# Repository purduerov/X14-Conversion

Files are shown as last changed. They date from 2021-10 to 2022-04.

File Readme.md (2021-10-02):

# Readme for X14-Conversion

Whenever you make a new part, download the datasheet and save it here _**and**_ with the part in the parts library

Always pull other people's changes before beginning to work
`git pull`

Be sure to push your changes after  working on them. Run:
1. `git add .` to add any files in this directory or a subdirectory
or `git add -u` to add any modified files
2. (Optional) `git clean -nX` to see what ignored files can be removed
	`git clean -fX` removes ignored files (Eagle backups)
3. `git commit -m "helpful commit message"` with a description of the work that you did
4. `git push` to push your work to github

Other helpful commands
* `git status` says information about modified and staged files
* `git log` shows the recent commits of the repository
* `git log filename.extension` show the recent commits for just that file
* `git checkout first-couple-letter-of-commit-id` lets you go back to a previous version
* `git checkout master` brings you back to the latest commit
* `git tag` lists the tags
* `git tag -a orderX -m "the version of the board placed for the X'th order"` tag a specific commit
* `git push --tags` needed to push tags to remote
* `git show orderX` show the commit log for the given tag
* `git checkout orderX` go back and interact with the files at the tagged commit

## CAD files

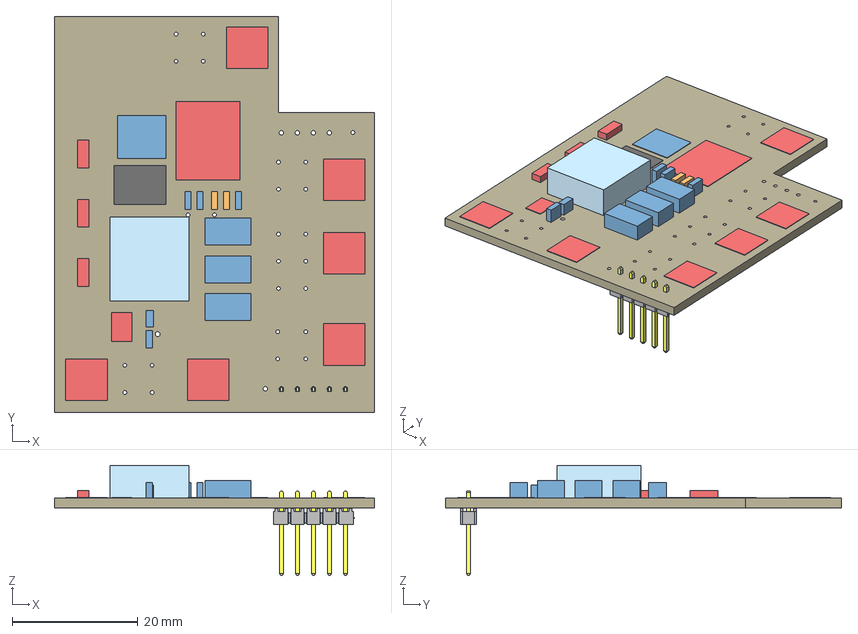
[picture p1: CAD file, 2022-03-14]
X14-Conversion.step
50.8 x 62.9 x 17.5 mm
Board
15uH
AZ1117C-3.3
3.3V_TESTPOINT
5.2V_TESTPOINT
12V_TESTPOINT
GND_TESTPOINT x 3
1kΩ x 2
0.1uF x 4
22uF
550mV 5A
120uF 25mΩ
_TSW-105-14-G-S_body
_T-1S6-08-TSW-1-14-5-S
BUCK,LM2678S-ADJ
150uF x 3
1X02 x 3

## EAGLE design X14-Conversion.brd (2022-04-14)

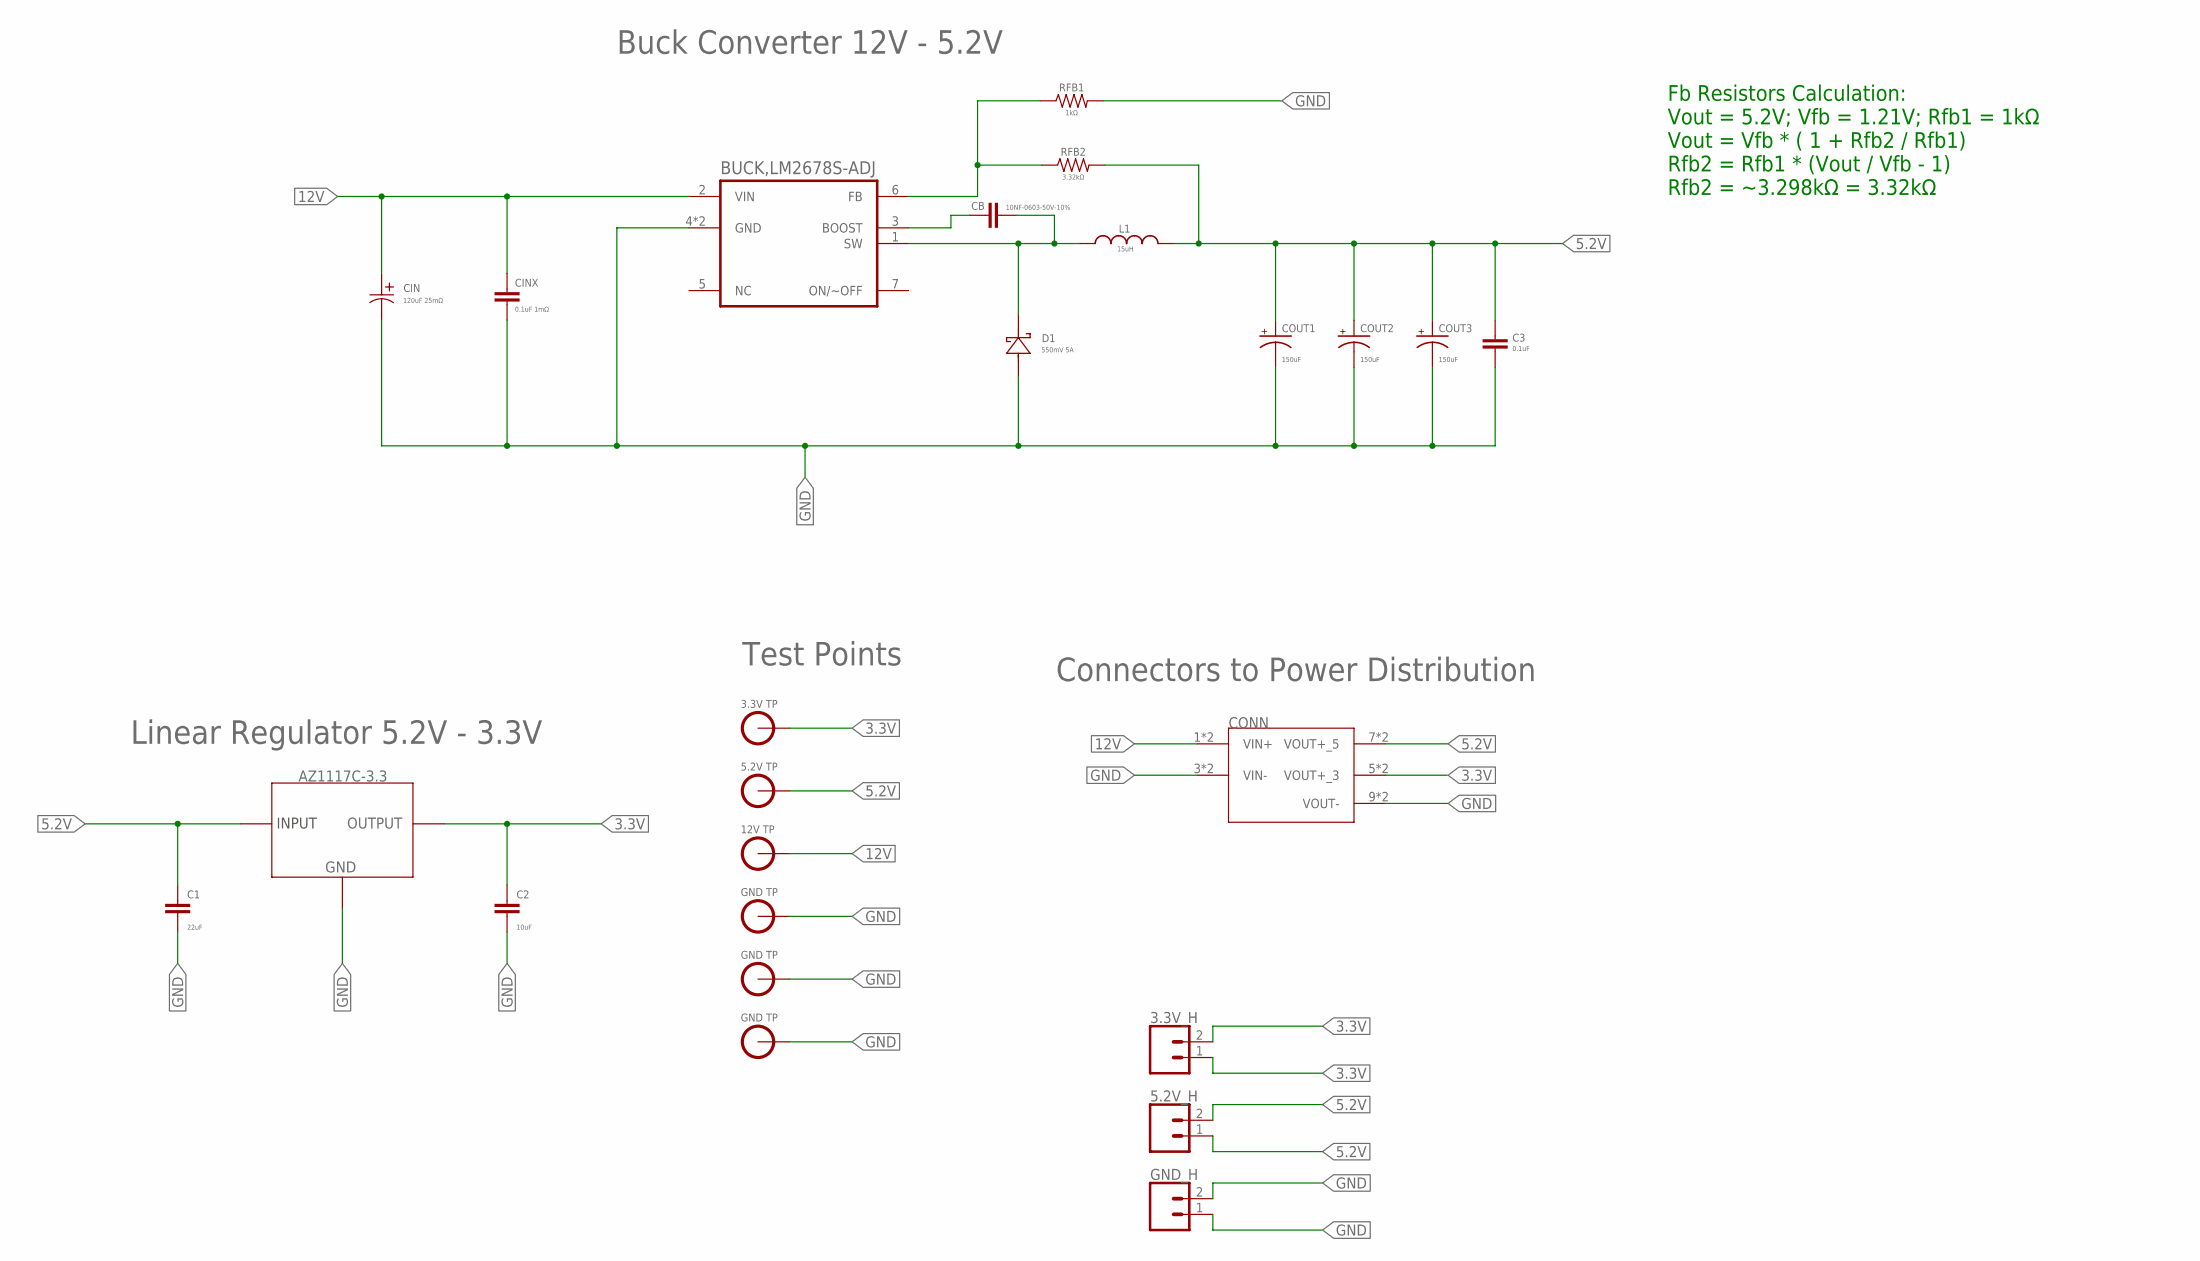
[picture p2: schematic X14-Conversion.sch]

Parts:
3.3V_H, 5.2V_H: CONN_02; 1X02
AZ1117C: AZ1117C-3.3; SOT150P410X160-3N
C1: 22uF; 0805
C2: 10uF; 0603
C3: 0.1uF; 0603
CB: 10NF-0603-50V-10%; 0603
CIN: 120uF 25mΩ; PCAP_SVP_C6_PAN
CINX: 0.1uF 1mΩ; 0603
CONN: CONVERSION-DISTRIBUTION; TSW-105-05-G-S(C-D)
COUT1, COUT2, COUT3: 150uF; 2917(7343-31-METRIC)
D1: 550mV 5A; CDBG520-G
GND_H: CONN_02; 1X02
L1: 15uH; HCMA1305
RFB1: 1kΩ; 0603
RFB2: 3.32kΩ; 0603
U1: BUCK,LM2678S-ADJ; TO127P1435X464-8N
U$2: 3.3V_TESTPOINT
U$3: 5.2V_TESTPOINT
U$4: 12V_TESTPOINT
U$5, U$6, U$7: GND_TESTPOINT

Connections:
3.3V: 3.3V_H.1, 3.3V_H.2, AZ1117C.2 (OUTPUT), AZ1117C.4 (OUTPUT), C2.1, CONN.5 (VOUT+_3), CONN.6 (VOUT+_3), U$2.3.3V
5.2V: 5.2V_H.1, 5.2V_H.2, AZ1117C.3 (INPUT), C1.1, C3.1, CONN.7 (VOUT+_5), CONN.8 (VOUT+_5), COUT1.+, COUT2.+, COUT3.+, L1.2, RFB2.2, U$3.5.2V
12V: CIN.1, CINX.1, CONN.1 (VIN+), CONN.2 (VIN+), U1.2 (VIN), U$4.12V
CB: CB.1, U1.3 (BOOST)
FB: RFB1.1, RFB2.1, U1.6 (FB)
GND: AZ1117C.1 (GND), C1.2, C2.2, C3.2, CIN.2, CINX.2, CONN.3 (VIN-), CONN.4 (VIN-), CONN.9 (VOUT-), CONN.10 (VOUT-), COUT1.-, COUT2.-, COUT3.-, D1.2, GND_H.1, GND_H.2, RFB1.2, U1.4 (GND), U1.8 (GND), U$5.GND, U$6.GND, U$7.GND
SW: CB.2, D1.1, L1.1, U1.1 (SW)

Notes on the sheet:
Buck Converter 12V - 5.2V
Connectors to Power Distribution
Linear Regulator 5.2V - 3.3V
Test Points
Fb Resistors Calculation: Vout = 5.2V; Vfb = 1.21V; Rfb1 = 1kΩ Vout = Vfb * ( 1 + Rfb2 / Rfb1) Rfb2 = Rfb1 * (Vout / Vfb - 1) Rfb2 = ~3.298kΩ = 3.32kΩ

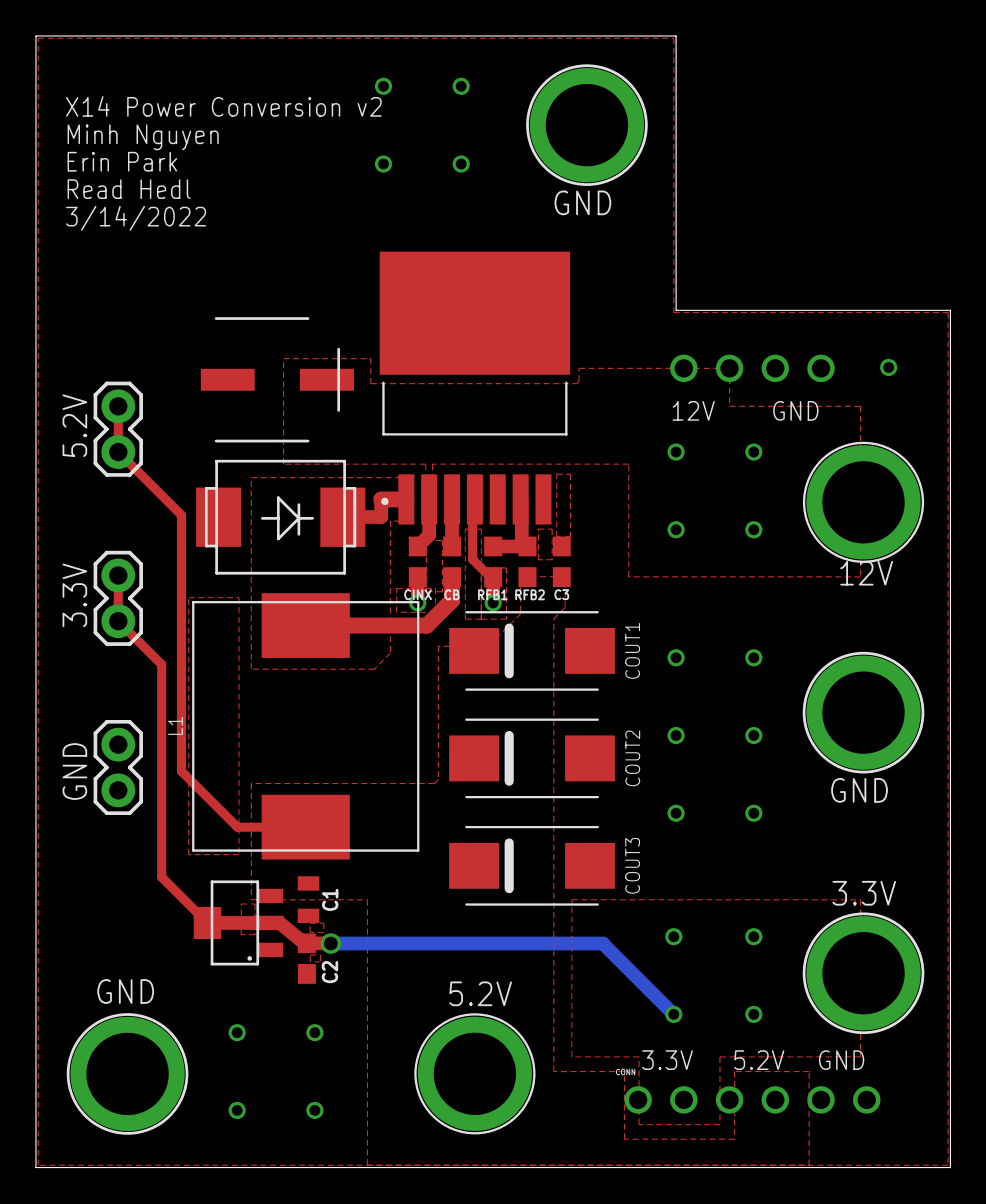
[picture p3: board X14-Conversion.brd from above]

Board: 2 copper layers, 50.8 x 62.9 mm, 25 parts (1 on the bottom side), 7 nets.

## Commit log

2021-10-02 Created files
    [X14-Conversion.brd, X14-Conversion.sch]
2021-10-13 Added conversion board library
    [X14-Conversion.brd, X14-Conversion.sch]
2021-10-14 Update new parts library
    [X14-Conversion.brd, X14-Conversion.sch]
2021-10-14 Complete Schematic for LM2678
    [X14-Conversion.brd, X14-Conversion.sch]
2021-10-20 Fix Schematic
    [X14-Conversion.brd, X14-Conversion.sch]
2021-10-20 Completing Schematic
    [X14-Conversion.brd, X14-Conversion.sch]
2021-10-20 Completing Schematic (1) and Upload Datasheets
    [X14-Conversion.brd, X14-Conversion.sch]
2021-10-21 Update Datasheets Library and Finalize schematics
    [X14-Conversion.sch]
2021-10-30 Fix Schematic, add test points, screw terminals and connectors
    [X14-Conversion.brd, X14-Conversion.sch]
2021-11-06 Fix capacitors and resistors to Sparkfun components
    [X14-Conversion.brd, X14-Conversion.sch]
2021-11-06 Fix capacitors on Linear Regulator
    [X14-Conversion.brd, X14-Conversion.sch]
2021-11-06 Fix Footprints
    [X14-Conversion.brd, X14-Conversion.sch]
2021-11-11 Fix footprints and update dimension
    [X14-Conversion.brd, X14-Conversion.sch]
2021-11-21 Complete Board Layout
    [X14-Conversion.brd, X14-Conversion.sch]
2021-11-28 Completet Board Layout (1)
    [X14-Conversion.brd, X14-Conversion.sch]
2021-11-30 Fix Board Layout
    [X14-Conversion.brd, X14-Conversion.sch]
2021-12-01 isolate updated
    [X14-Conversion.brd]
2021-12-04 Fix Board
    [X14-Conversion.brd, X14-Conversion.sch]
2021-12-04 Fix 45 Degree and minor details
    [X14-Conversion.brd, X14-Conversion.sch]
2021-12-04 Finalizing board for Alumni Design Review
    [X14-Conversion.brd, X14-Conversion.sch]
2021-12-04 Fix Testpoints
    [X14-Conversion.brd, X14-Conversion.sch]
2021-12-04 Fix board with new DRC
    [X14-Conversion.brd]
2021-12-17 Change Output Capacitors
    [X14-Conversion.brd, X14-Conversion.sch]
2021-12-18 Fix & complete board
    [X14-Conversion.brd, X14-Conversion.sch]
2021-12-20 Complete Board
    [X14-Conversion.brd]
2022-01-02 Fix board layout based on Grant's comments
    [X14-Conversion.brd, X14-Conversion.sch]
2022-01-04 small adjustments
    [X14-Conversion.brd]
2022-01-07 added silkscreen
    [X14-Conversion.brd]
2022-03-10 Reduce board size
    [X14-Conversion.brd, X14-Conversion.sch]
2022-03-14 add 1x2 headers to board
    [X14-Conversion.brd, X14-Conversion.sch]
2022-03-14 Adjusted Label, Exported STEP
    [X14-Conversion.brd, X14-Conversion.step]
2022-03-14 fixed STP file
    [X14-Conversion.step]
2022-04-14 Update label position
    [X14-Conversion.brd]

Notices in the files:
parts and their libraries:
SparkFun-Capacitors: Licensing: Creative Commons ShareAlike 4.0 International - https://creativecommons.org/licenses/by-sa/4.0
